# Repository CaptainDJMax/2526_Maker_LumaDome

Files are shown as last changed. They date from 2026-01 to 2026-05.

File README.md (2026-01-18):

# 2526_Maker_LumaDome

##  Présentation du projet
**LumaDome** est une lampe d'ambiance connectée et intelligente. L'objectif est d'allier esthétique et technique pour afficher des messages dynamiques. Conçue comme un objet design hybride, elle associe une base imprimée en 3D, un abat-jour textile structuré par découpe laser et l'électronique sur mesure et la gestion d'énergie.

Au-delà de l'esthétique, l'objectif est de créer une interface lumineuse capable de :
* Afficher des **notifications visuelles** (ex: simulateur d'aube au réveil).
* Diffuser des **messages personnalisés** envoyés en Bluetooth depuis un smartphone.
* Être totalement **nomade** grâce à une batterie intégrée.

## 🛠 Architecture Technique
Ce projet mobilise 4 axes principaux :
1.  **Mécanique :** Base cylindrique (Impression 3D) contenant l'électronique + Structure haute (Découpe Laser) supportant le textile.
2.  **Électronique :** PCB sur mesure avec microcontrôleur (type ESP32) pour la gestion LED et Bluetooth.
3.  **Énergie :** Système autonome sur batterie LiPo avec gestion de charge (BMS).
4.  **Habillage :** Travail du textile (Couture) pour la diffusion de la lumière.

##  Rétroplanning Prévisionnel 🔗[02_Gestion_Projet/RetroPlanning.md]

[Cliquez ici pour voir le rétroplanning complet et détaillé](./02_Gestion_Projet/RetroPlanning.md)

Ce planning s'aligne sur les séances de formation technique du semestre.

| Date | Phase | Objectifs spécifiques LumaDome |
| :--- | :--- | :--- |
| **19 Janv** | CAD (Conception) | Modélisation 3D de la base (support PCB) et esquisse de la structure laser. |
| **22 Janv** | 3D Print | Lancement de l'impression du prototype de la base. |
| **26 Janv** | Laser Cut | Découpe du squelette/cadre pour l'abat-jour. |
| **29 Janv** | PCB Design | Conception de la carte électronique (ESP32 + Driver LED). |
| **05 Fév** | Batterie (LiPo) | Dimensionnement de la batterie et intégration du BMS. |
| **09 Fév** | Couture | Patronage et assemblage du tissu sur la structure laser. |
| **Fév - Mars** |  Code & Finalisations| Développement du firmware (Bluetooth & Animations) + finalisation des choses pas terminer|
| **Avril** | Finalisation | Assemblage final, finitions et tournage vidéo. |

```mermaid
gantt
    title Rétro-Planning LumaDome (2026)
    dateFormat  YYYY-MM-DD
    axisFormat  %d/%m
    excludes    weekends

    section Phase 1 : Formation & Proto
    Git & Concept (Fait)       :done,    p1_git, 2026-01-15, 1d
    CAD Base 3D (En cours)     :active,  p1_cad, 2026-01-19, 3d
    3D Print (Lancement)       :         p1_3d,  2026-01-22, 1d
    Laser Cut (Structure)      :         p1_las, 2026-01-26, 3d
    PCB Design (KiCad)         :         p1_pcb, 2026-01-29, 4d
    Soudure & Routage          :         p1_sou, 2026-02-02, 3d
    Batterie LiPo & BMS        :         p1_bat, 2026-02-05, 4d
    Couture (Habillage)        :         p1_cou, 2026-02-09, 5d

    section Phase 2 : Dév. LumaDome
    Intégration Méca/Elec      :         p2_int, 2026-02-16, 3d
    Code (Hello World LED)     :         p2_dev1, 2026-02-19, 10d
    Code (Bluetooth BLE)       :         p2_dev2, 2026-03-09, 3d
    Debug & Tests Autonomie    :         p2_deb, 2026-03-12, 4d
    Finitions Tissu            :         p2_fin, 2026-03-16, 3d
    Code (Animations)          :         p2_dev3, 2026-03-19, 4d
    Assemblage Final           :         p2_ass, 2026-03-23, 3d
    Tournage Vidéo             :         p2_vid, 2026-03-26, 4d
    Derniers ajustements       :         p2_adj, 2026-03-30, 7d
    Prép. Soutenance           :         p2_sou, 2026-04-02, 7d
    
    section Jalons
    SOUTENANCE FINALE          :crit, milestone, 2026-04-13, 0d
```
---

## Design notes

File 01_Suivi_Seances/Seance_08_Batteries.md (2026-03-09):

# Séance 8 : 19 Février 2026 - Utilisation et Fabrication de Batteries

##  Objectifs de la séance
* Comprendre les différentes chimies de batteries (Li-ion, LiFePO4).
* Maîtriser le dimensionnement électrique (Capacité, Taux de décharge "C", Série/Parallèle).
* Apprendre les règles de sécurité et les étapes de fabrication d'un pack batterie sur mesure.

##  Résumé du cours

### 1. Pourquoi fabriquer sa propre batterie ?
Créer son propre pack présente plusieurs avantages majeurs :
* **Forme sur mesure :** Permet d'adapter parfaitement la batterie à la coque de notre projet (ex: intégration dans un dôme).
* **Maîtrise du processus :** On choisit la qualité des composants et on réduit les coûts.
* **Écologie / Sécurité :** L'usage de piles rechargeables est beaucoup plus pertinent et économique à long terme (notamment pour les jouets d'enfants ou les gros projets).

### 2. Les chimies et tensions nominales
Il est vital de connaître la chimie pour bien configurer son chargeur et son BMS :
* **Lithium-Ion (Li-ion) :** Tension nominale d'environ **3.7V** (varie de 3.0V vide à 4.2V pleine).
* **Lithium Fer Phosphate (LiFePO4) :** Tension nominale d'environ **3.2V** (chimie très stable et sécurisée).

### 3. Le Taux de décharge / charge (Le "C-Rate")
*Note sur la Slide 11 du cours :*
Le "C" représente la **Capacité** de la batterie. Il définit les limites de courant qu'elle peut encaisser.
* **Décharge (Max Discharge Rate) :** Si une batterie de 4000 mAh a une décharge de 30C, le courant maximal autorisé est : $4 \text{ Ah} \times 30 = \mathbf{120 \text{ Ampères}}$.
* **Charge (Max Charge Rate) :** Une indication de "3C" signifie qu'on peut la charger à 3 fois sa capacité (ici 12A). *Règle de sécurité :* Si on ne connaît pas la valeur, on charge toujours à **1C maximum** pour ne pas abîmer la cellule.

### 4. Configuration S et P
L'assemblage des cellules définit la puissance du pack :
* **S (Série) :** Additionne la tension. Exemple : "4S" = 4 batteries à la suite.
* **P (Parallèle) :** Additionne la capacité (et le courant de décharge). "4S1P" signifie un pack de 4 batteries en série, avec une seule rangée (pas de cellules doublées).

## 🛠️ Travaux Pratiques : Le Pack Batterie LumaDome
Pour mon projet, j'ai besoin d'une alimentation capable de délivrer **12V et au moins 5A** pour alimenter le convertisseur Buck des LEDs NeoPixel.

**Choix technique :** J'ai opté pour un **Pack 4S** (4 cellules en série).
* *Cellules utilisées :* Samsung INR18650-35E (3.7V, 3450mAh, décharge 8A).
* *Protection :* Un BMS 4S 20A sera intégré pour équilibrer la charge et protéger contre les courts-circuits.

**État d'avancement du TP :**
Je n'ai pas encore procédé à la soudure par points des lamelles de nickel. Actuellement, je me concentre sur la conception mécanique.
* **Modélisation 3D :** Je suis en train de designer la coque (support de batterie) sur CAD. Cette pièce imprimée en 3D permettra d'accueillir et de caler fermement les 4 piles avant de procéder à l'assemblage définitif (Soudure, BMS, Kapton et Gaine thermorétractable).

## ✅ Tâches effectuées
- [x] Dimensionnement du pack batterie pour le projet (Configuration 4S).
- [x] Début de la conception 3D du support de piles 18650.
- [ ] Impression 3D du support (À faire).
- [ ] Soudure par points et assemblage du pack (À faire).

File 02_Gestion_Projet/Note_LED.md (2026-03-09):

###  Note Technique : Dimensionnement des LEDs (Ref: Adafruit 1138)

#### 1. Choix du Matériel (Éclairage)
* **Référence retenue :** Adafruit 1138-4m (NeoPixel Digital RGB LED Strip - White PCB).
* **Spécifications :** Alimentation **5V DC**, densité standard de **60 LEDs/mètre**, adressables individuellement (WS2812B/SK6812).
* **Avantages :** La bobine de 4 mètres permet de couvrir le projet avec une seule bande .

#### 2. Calculs de Dimensionnement (Surface & Longueur)
Pour créer une grille lumineuse homogène sur la surface du LumaDome ($31 160.67 \text{ mm}^2$) :
* **Espacement :** À 60 LEDs par mètre, l'écart entre chaque puce LED est de **16.5 mm**.
* **aire LED théorique :** Longueur x largeur = $16,5 * 12,5$ = **206,25 mm²**.
* **Verdict :** Pour tapisser parfaitement la surface, environ $31 160.67 / 206,25 = 152$ LED nécessaires. L'achat de la bobine de 4 mètres garantit d'avoir suffisamment de matière.

#### 3.  Bilan de Puissance & Électronique.
* **Consommation (pour 125 LED) :** Chaque LED consomme jusqu'à 60mA (en blanc luminosité max). $125 \times 0.06\text{A}$ = **7.5 Ampères** (soit environ 37.5 Watts).

#### 4. Intégration sur le PCB
* **Alimentation (Convertisseur Buck) :** Pour passer de la batterie 4S (~14.8V) au 5V requis par les LEDs, un module Step-Down 5V capable de fournir **10 Ampères** de manière stable sera parfait (il y a une bonne marge de sécurité).
* **Routage KiCad :** Un courant de 7.5 A est parfaitement gérable, mais il faut appliquer la règle de dimensionnement vue en cours : **1 Via supporte environ 1 Ampère**. Il faudra donc utiliser des pistes d'alimentation larges et placer plusieurs Vias pour les changements de couche.

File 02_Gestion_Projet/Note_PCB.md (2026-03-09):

# Note Technique : Nomenclature (BOM) et Rôle des Composants du PCB

Cette note détaille l'ensemble des composants nécessaires à la conception du circuit imprimé (PCB) du LumaDome, ainsi que leur rôle spécifique dans l'architecture électronique.

## Nomenclature des composants (BOM)

| Catégorie | Composant | Référence / Détails | Rôle principal |
| --- | --- | --- | --- |
| **Énergie** | **Secteur 12V** | Bloc alimentation DC 12V (2.5 A) | Alimentation fixe (Jack DC). |
| **Énergie** | **Batterie 4S** | 4x 18650 Samsung INR18650-35E | Source nomade (**14.8V** nominal). |
| **Énergie** | **Régulateur 5V** |  | Alimente les LEDs (conversion 16V -> 5V). |
| **Énergie** | **Régulateur 3.3V** |  | Alimente l'ESP32 (conversion 5V -> 3.3V). |
| **Cerveau** | **Microcontrôleur** | **ESP32-WROOM-32E-N4** | Cerveau Wi-Fi/BT et gestion des LEDs. |
| **Interface** | **Connecteur JTAG** | **Header 2x5 (10 pins)** | Interface pour l'ESP-Prog 2 (Debug/Flash). |
| **Interface** | **Connecteur LED** | Bornier ou JST SM 3 pins | Sortie vers le ruban Adafruit 1138. |
| **Logique** | **Level Shifter** | **SN74AHCT125** | Traduit le signal Data 3.3V vers 5V. |
| **Contrôle** | **Boutons** | Poussoirs tactiles 6mm | Mode, Luminosité, Reset, Boot. |
| **Outil** | **ESP-Prog 2** | Programmateur | Programmateur externe USB. |

---

## 1.  Le Cerveau et la Programmation

* **Le Microcontrôleur : ESP32-WROOM-32E-N4**
  * *Rôle :* C'est le cerveau du projet. Il exécute le code en C (ESP-IDF), génère les signaux pour animer les LEDs, et lit les appuis sur les boutons. Il intègre nativement le Wi-Fi et le Bluetooth.
* **Le Connecteur JTAG / UART : Header 2x5 pins/broches (Pas de 2.54mm ou 1.27mm)**
  * *Rôle :* C'est la "prise diagnostic" du PCB. Elle permet de relier la carte à l'ordinateur pour injecter le code et lire les erreurs.
* **Le Programmateur Externe : ESP-PROG-2**
  * *Rôle :* Outil physique officiel d'Espressif (qui ne reste pas sur la lampe). Il fait le pont entre le port USB de l'ordinateur et le connecteur JTAG du PCB pour flasher et déboguer le code de l'ESP32.

## 2.  L'Alimentation et l'Énergie

* **L'Entrée Secteur : Connecteur USB-C (avec module Trigger 12V)**
  * *Rôle :* Permet de brancher un chargeur mural standard (fournissant du 12V DC) pour utiliser la lampe à la maison sans vider la batterie.
* **L'Entrée Batterie : Connecteur JST**
  * *Rôle :* Relie le pack batterie maison 4S (14.8V nominal / 16.8V max) au circuit.
* **Le Sélecteur de Source : Interrupteur à bascule (SPDT - 3 broches)**
  * *Rôle :* Sécurité matérielle. Il permet de basculer physiquement l'alimentation de la lampe soit sur la Batterie, soit sur le Secteur, empêchant les deux de se court-circuiter.
* **Le Grand Régulateur 5V**
  * *Rôle :* Il prend le 12V (secteur) ou le 16.8V (batterie) et le rabaisse à un **5V** très puissant (capable de fournir au moins 7 à 10 Ampères) pour alimenter l'intégralité du ruban LED.
* **Le Petit Régulateur 3.3V**
  * *Rôle :* Il prend le 12V et le rabaisse en un **3.3V** très propre et stable, uniquement pour l'ESP32 qui ne supporte pas le 5V.

## 3.  Interface et Lumière

* **Le Level Shifter : SN74AHCT125N (ou 74AHCT125D en CMS)**
  * *Rôle :* Convertisseur de niveau logique ("traducteur"). L'ESP32 envoie les ordres de couleurs en 3.3V, mais les LEDs exigent un signal de 5V. Ce composant rehausse le signal instantanément pour éviter que les LEDs ne clignotent de manière erratique.
* **Le Connecteur Ruban LED : Connecteur JST SM (3 broches) ou Bornier à vis**
  * *Rôle :* Permet de brancher (et débrancher facilement) les 3 fils du ruban Adafruit 1138 (5V, Data, GND) à la carte mère.
* **Boutons Utilisateur : Boutons Poussoirs Tactiles (6x6mm)**
  * *Bouton "Mode" :* Relié à une broche de l'ESP32 pour changer les animations (ex: fondu, clignotement, couleur fixe).
  * *Bouton "Luminosité" :* Relié à une autre broche pour cycler entre différents niveaux d'intensité (ex: 25%, 50%, 100%).
* **Boutons Système : Boutons Poussoirs Tactiles**
  * *Bouton "Reset" (EN) :* Redémarre l'ESP32.

---

##  🛠️ Focus : Le Connecteur JTAG (2x5 pins)

Pour le LumaDome, nous abandonnons le connecteur UART simple pour une interface **JTAG professionnelle**. Cela permet non seulement de flasher le code, mais aussi de faire du **débogage en temps réel** (arrêt sur image du code, lecture des variables).

### A. Choix matériel

* **Type :** Barrette de broches mâle (**Pin Header 2x5**).
* **Pas (Pitch) :** **2.54 mm** (choisi pour la facilité de soudure manuelle).
* **Câblage :** Relié au port "JTAG" de l'**ESP-Prog 2** via une nappe 10 fils.

### B. Plan de connexion (Netlist) vers l'ESP32

Ce tableau définit comment relier le connecteur 2x5 aux broches du module ESP32-WROOM-32E dans KiCad :

| Broche Connecteur (2x5) | Signal JTAG | Broche ESP32-WROOM | Fonction |
| --- | --- | --- | --- |
| **1** | **VDD** | **3V3** | Alimentation logique |
| **2** | **TMS** | **GPIO 14** | Test Mode Select |
| **3** | **GND** | **GND** | Masse |
| **4** | **TCK** | **GPIO 13** | Test Clock |
| **5** | **GND** | **GND** | Masse |
| **6** | **TDO** | **GPIO 15** | Test Data Out |
| **7** | **NC** | - | Non connecté |
| **8** | **TDI** | **GPIO 12** | Test Data In |
| **9** | **GND** | **GND** | Masse |
| **10** | **RESET** | **EN** | Hard Reset automatique |

---

## 3. 💡 Recommandations pour la conception du PCB

###  Routage et Signaux

* **Détrompeur :** Marquer la **broche 1** sur le PCB avec un petit triangle blanc en sérigraphie pour éviter de brancher la nappe à l'envers.
* **Intégrité du signal :** Les pistes JTAG (TDI, TDO, TCK, TMS) transportent des signaux rapides. Il faut les router de manière directe et éviter de les faire passer trop près du régulateur Buck 5V pour limiter les parasites.

###  Gestion de la Puissance

* **Largeur des pistes :** Pour les 112 LEDs (consommation max **7,5 A**), utiliser des pistes de puissance d'au moins **3-4 mm** de large ou un plan de cuivre complet sur la face arrière.

---

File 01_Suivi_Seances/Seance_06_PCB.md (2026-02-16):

# Séance 6 : 2 Février 2026 - Conception de Circuit Imprimé (PCB)

##  Objectifs de la séance
* Comprendre la structure physique d'un PCB (Couches, FR4, Cuivre).
* Appréhender les bus de communication (UART, I2C, SPI).
* Maîtriser les règles de conception (Schematic & Layout) sous KiCad.
* Focus spécifique sur l'intégration de l'USB-C et les protections ESD.

##  Résumé du cours

### 1. Anatomie d'un PCB
Un circuit imprimé est un sandwich de plusieurs couches[cite: 19]:
* **Substrat  :** L'isolant rigide (fibre de verre + époxy) qui sert de support.
* **Cuivre (Copper) :** Les pistes conductrices. On parle de couches "Top" (Dessus) et "Bottom" (Dessous).
* **Vernis épargne (Soldermask) :** La couche (souvent verte) qui protège le cuivre et empêche l'étain de baver.
* **Sérigraphie (Silkscreen) :** Le texte blanc pour identifier les composants.

### 2. Workflow sous KiCad
La conception se fait en deux temps:
1.  **Schématique (Schematic) :** On dessine la logique du circuit avec des symboles.
2.  **Routage (Layout/PCB New) :** On transforme les symboles en empreintes physiques (Footprints) et on trace les pistes en cuivre.

### 3. Focus Technique : USB-C et Protections
Pour intégrer un port USB-C proprement (exemple pour alimenter notre carte), il faut respecter certaines règles dictées par le standard :
* **Réversibilité :** Pour que le câble fonctionne dans les deux sens, il faut connecter les broches **CC1** et **CC2** à la masse via deux résistances de **5.1kΩ** distinctes. Cela indique au chargeur qu'il doit fournir du 5V.
* **Protection ESD (Électrostatique) :** L'ajout d'un composant comme le **USBLC6-SC6** (réseau de 5 diodes) est recommandé pour protéger les lignes de données contre les pics de tension ou les mauvais branchements.
* **Diode TVS :** À placer sur l'alimentation pour absorber les surtensions transitoires.

### 4. Bonnes pratiques de Routage
* **Découplage :** Les condensateurs de découplage doivent être placés **au plus près** des broches d'alimentation du composant pour être efficaces.

* **Signaux rapides (USB/Data) :** Il faut router les pistes paires (D+/D-) avec la même longueur (Paires différentielles) pour éviter les décalages de signal.
* **Courant & Vias :**
    * Une règle empirique à retenir : **1 Via standard supporte environ 1A**.
    * La largeur des pistes doit être adaptée au courant qui les traverse (utiliser un calculateur).
* **Unités :** Attention aux datasheets !
    * `mm` = Millimètres.
    * `mil` = Millième de pouce (100 mil = 2.54 mm).

### 5. Astuces KiCad
* **PWR_FLAG :** Symbole spécial à ajouter sur le schéma pour dire au logiciel "Ceci est une source d'alimentation" et éviter les erreurs du DRC (Design Rules Checker).
* **MPN (Manufacturer Part Number) :** Pour tout composant non générique (hors résistances/condensateurs classiques), il est crucial de renseigner la référence fabricant exacte dans les propriétés pour faciliter la commande (BOM).

## 🛠️ Travaux Pratiques 
Conception KiCad
1.  **Schématique :**
    * Intégration du CH334F et du Quartz 12 MHz.
    * Ajout des protections ESD (USBLC6-2) sur toutes les lignes de données.
    * Utilisation du symbole `PWR_FLAG` pour valider les entrées d'alimentation lors du check électrique (ERC).
2.  **Routage (Layout) - Règles Avancées :**
    * **Stackup 4 Couches :** Top (Signaux) / In1 (GND Plane) / In2 (Power Plane) / Bottom (Signaux + Pogo).
    * **Signal Integrity (USB High Speed 480Mbps) :**
        * **Length Matching (Skew) :** Ajustement des longueurs de pistes (D+ vs D-) via des "méandres" (zigzags) pour garantir une tolérance < 0.15mm.
    * **Mécanique :** Placement précis des Pogo-pins selon le DXF officiel du Raspberry Pi Zero.

###  État d'avancement
Le projet est en phase finale : Schéma validé, Routage terminé (y compris les méandres), DRC (Design Rule Check) en cours de correction.

##  Impact sur le projet LumaDome
Ce TP m'a permis de valider la conception USB-C. Pour mon projet personnel (LumaDome), j'appliquerai les mêmes règles (Résistances 5.1kΩ + USBLC6) pour la prise de charge et la programmation si besoin dans mon projet.

## ✅ Tâches effectuées
- [x] Cours théorique sur les bus (I2C, UART) et les couches PCB.
- [x] Analyse du schéma de référence pour l'USB-C (Résistances CC + ESD).
- [x] Saisie du schématique complet du Hub CH334F sous KiCad.
- [x] Placement et routage complexe (4 couches + Paires différentielles).
- [ ] Création du projet KiCad pour le LumaDome (À faire).

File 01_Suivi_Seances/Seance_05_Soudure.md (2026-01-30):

# Séance 5 : 29 Janvier 2026 - Soudure & Assemblage PCB

## Objectifs de la séance
* Comprendre la théorie du brasage (Soudure) : mouillage, flux, alliages.
* Apprendre le processus industriel CMS (Composants Montés en Surface).
* Pratiquer l'assemblage manuel (Fer à souder) et la refusion (Four).

## Résumé du cours
### 1. Théorie de la soudure
Le brasage est un procédé d'assemblage permanent établissant une liaison métallique.
* **Le Flux :** Indispensable, il sert à décaper les surfaces (enlever l'oxyde), favoriser le mouillage et protéger le métal lors de la chauffe.
* **Sécurité :** Les fumées de soudure sont nocives (colophane). Il faut impérativement travailler dans une zone ventilée et se laver les mains après manipulation (risque plomb).

### 2. Procédé CMS (Surface) vs Traversant
* **Soudure Manuelle (Traversant) :** On utilise un fer chauffé entre **350°C et 400°C**. La technique consiste à chauffer simultanément la pastille et la patte du composant avant d'apporter l'étain.
* **Procédé Reflow (CMS) :** Utilisé pour les composants de surface.
    * **Pâte à braser :** Mélange de billes d'étain et de flux. Elle a une durée de vie limitée une fois sortie du frigo.
    * **Stencil (Pochoir) :** Feuille d'inox découpée au laser permettant de déposer la pâte précisément sur les empreintes du PCB.
    * **Four à refusion :** Suit un profil thermique précis : Préchauffage (montée en température), Soak (activation du flux), Reflow (fusion de l'alliage) et Refroidissement.

## Travaux Pratiques : Assemblage PCB
*Travail réalisé en trinôme avec Elise FIRMIN et Emilie ZHENG.*

### Étape 1 : Composants CMS (Surface)
1.  **Dépôt de pâte :** Réalisé par les encadrants à l'aide du stencil.
2.  **Placement (Pick & Place) :**
    * Pendant que mes camarades récupéraient et triaient les composants nécessaires dans le FabLab, j'ai assuré le placement des composants sur le PCB.
    * =Utilisation de brucelles pour déposer les composants sur la pâte à braser sans l'étaler=.
3.  **Cuisson :** Passage de la carte dans le four à refusion pour braser tous les composants d'un coup.

### Étape 2 : Composants Traversants & Finitions
Après la sortie du four, nous avons terminé la carte manuellement :
* **Soudure au fer :** Fixation des connecteurs traversants (headers).
* **Cas particulier des Boutons Poussoirs :** Nous les avons soudés à la main **après** le passage au four.
    * *Raison technique :* Lors d'essais précédents, le plastique des boutons fondait à cause de la chaleur du four, rendant le mécanisme inopérant.

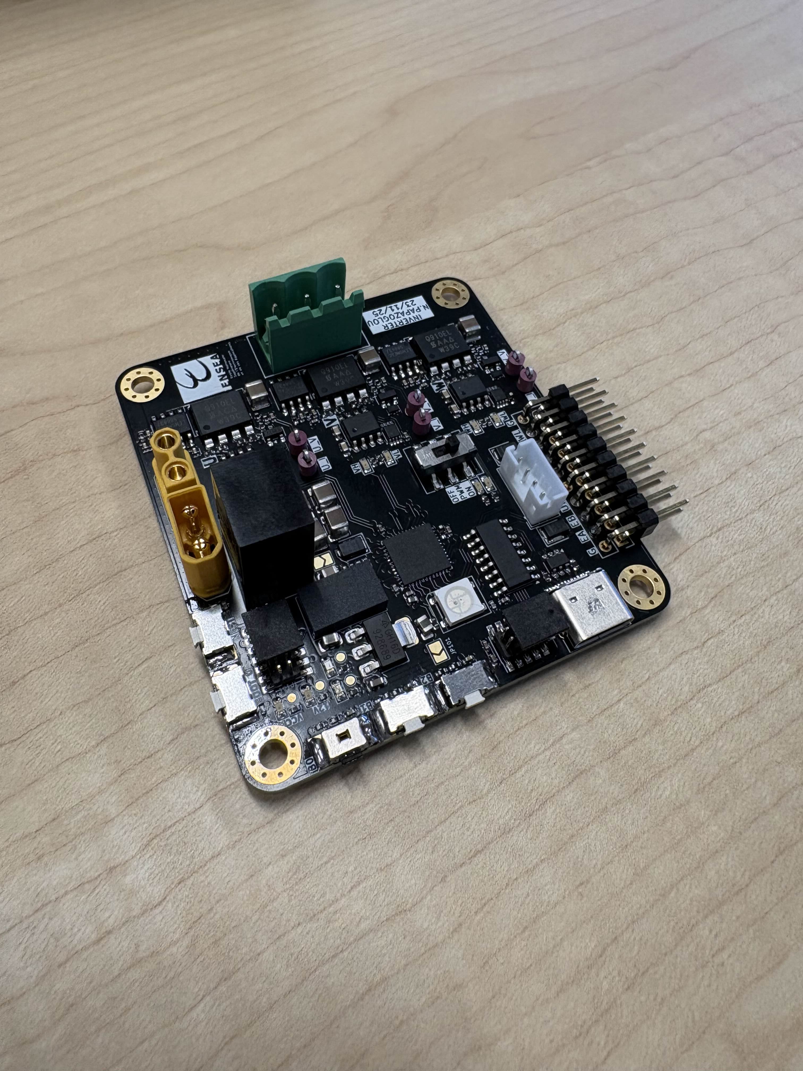
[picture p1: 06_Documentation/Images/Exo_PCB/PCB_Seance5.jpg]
Photo de notre PCB assemblé


## Notes importantes pour le Projet LumaDome

### Électronique (BOM)
Pour la commande des composants de mon projet personnel :
* Il faut impérativement renseigner la **référence fabricant (MPN - Manufacturer Part Number)** pour tous les composants (CI, Connecteurs, Leds).
* *Exception :* Pour les **résistances**, la valeur simple suffit (ex: 10kΩ, 220Ω).

### Mécanique (Vis)
Mise à jour des contraintes pour la modélisation 3D (Base) :
* Le stock disponible contient 1000 vis de **16mm**.
* **Action CAD :** Je dois adapter mes épaisseurs et rajouter **2mm** de marge aux joints d'assemblage pour être sûr que ces vis serrent correctement sans dépasser ou être trop courtes.

## ✅ Tâches effectuées
- [x] Placement des composants CMS sur pâte à braser.
- [x] Soudure manuelle des traversants.
- [x] Validation visuelle des joints de soudure (brillants et lisses).
- [ ] Mise à jour du BOM LumaDome avec les MPN.
- [ ] Correction du CAD Base (Tolérance vis 16mm).

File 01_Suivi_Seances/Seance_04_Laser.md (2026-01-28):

# Séance 4 : 26 Janvier 2026 - Découpe Laser

## Objectifs de la séance
* Comprendre le fonctionnement et les dangers d'une découpeuse laser CO2.
* Connaître les paramètres de coupe. 

## Résumé du cours

### 1. Principe et Machine
Nous utilisons une **Laser CO2** au FabLab.
* **Fonctionnement :** Un tube génère un faisceau laser (infrarouge) qui est dirigé par un jeu de miroirs jusqu'à la tête de découpe, où une lentille le focalise en un point très chaud.
* **Matériaux compatibles :** Principalement les matériaux organiques comme le bois (MDF, Contreplaqué), le carton, le cuir et les plastiques comme l'Acrylique (PMMA).
* **Sécurité & Environnement :**
    * C'est une machine de **Classe 4** (Risque d'incendie et de brûlure).
    * **Interdiction stricte :** Ne jamais couper de PVC ou Vinyle (dégage du chlore gazeux mortel pour l'homme et la machine).
    * **Ventilation :** Il y a de fortes odeurs après la découpe (bois brûlé/plastique fondu), il faut attendre avant d'ouvrir le capot.

### 2. Les 3 Paramètres Cruciaux
Pour réussir une découpe ou une gravure, il faut régler trois variables dans le logiciel :
1.  **Puissance (Power) :** L'intensité du rayon (en %). Trop fort = brûlures ; Trop faible = ne traverse pas.
2.  **Vitesse (Speed) :** La rapidité de déplacement de la tête.
    * *Coupe (Vecteur) :* Vitesse lente / Puissance élevée.
    * *Gravure (Raster) :* Vitesse rapide / Puissance modérée.
3.  **Fréquence (PPI/Hz) :** Le nombre d'impulsions par seconde. Une fréquence élevée donne un bord plus net (poli) sur l'acrylique.

### 3. Astuces de Conception
*  Le laser a une épaisseur (environ 0.1 - 0.2mm). Si on veut faire des gravures mettre une forte épaisseur au lieu d'épaisseur fine pour réaliser des gravures
* **Assemblages malins :**
    * *Notches :* Créneaux pour emboîter des plaques à 90°.
    * *Captive Nut (Écrou prisonnier) :* Découper une forme en "T" dans le bois pour y glisser un écrou métallique et pouvoir visser solidement (vu en cours).
    * *Living Hinge :* Motifs spécifiques permettant de plier du bois rigide.

##  Application au Projet LumaDome
La découpe laser servira à créer le **squelette** de l'abat-jour.

* **Design :** Conception de "couples" (comme sur un bateau) ou d'anneaux concentriques en MDF 3mm.
* **Assemblage :** Je vais utiliser la technique des **encoches (Notches)** pour assembler la structure laser sur la base imprimée en 3D.
* **Fixation Tissu :** Je prévois des petits trous dans la découpe laser pour pouvoir coudre le tissu directement sur le bois plus tard.

### TP Pratique : La "Useless Box"

En parallèle de l'apprentissage machine, j'ai réalisé un projet complet : une **Useless Box** . Ce projet m'a permis de lier la conception 3D et la fabrication réelle.

**1. Conception (Onshape) :**
J'ai modélisé l'intégralité du système avant fabrication pour valider les dimensions :
* **Le Boîtier :** Structure conçue pour être découpée au laser (assemblage par encoches/créneaux).
* **Les Supports Internes :** Conception sur mesure du support pour la pile et du berceau pour le moteur DC.
* **Le Mécanisme :** Modélisation du bras  qui vient physiquement basculer l'interrupteur pour inverser le sens de reotation du moteur et couper le circuit lors de la pose sur le levier à moustache.

**2. Composants utilisés :**
* Moteur DC + Support imprimé/découpé.
* Pile (Alimentation) + Logement.
* Interrupteur à levier (Toggle Switch).

**3. Assemblage & Résultat :**
Après la découpe et l'impression des supports, j'ai assemblé le tout. Le réglage de la course du levier (la moustache) a été l'étape clé pour qu'il touche parfaitement l'interrupteur.

**Galerie du projet :**

*Vue d'ensemble de la boîte fermée :*
Useless Box - Extérieur

*Vue interne (Mécanisme et Supports) :*
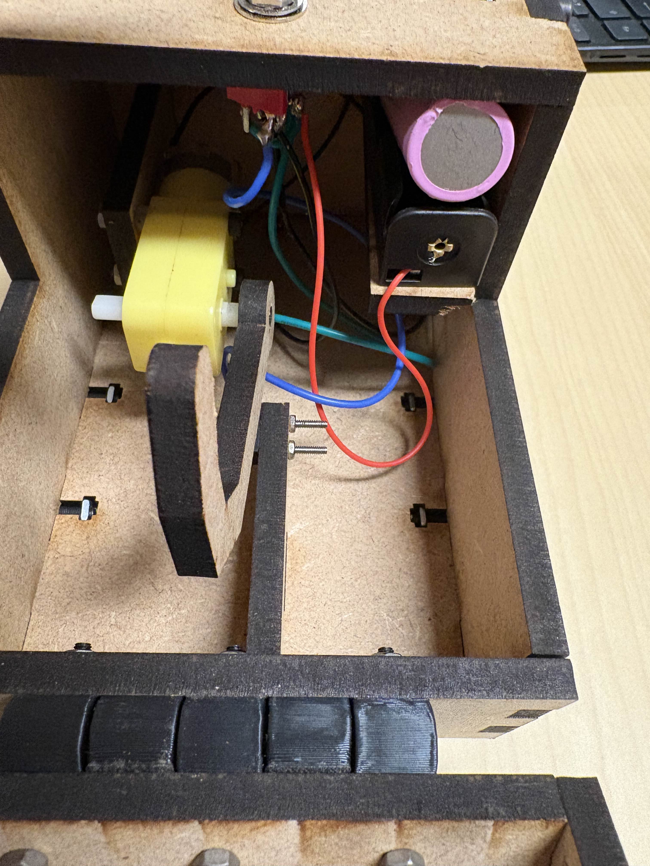
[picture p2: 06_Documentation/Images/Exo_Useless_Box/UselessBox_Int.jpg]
Mécanisme Interne


**Démonstration :**
[Vidéo du fonctionnement en action](../06_Documentation/Video/Exo_Useless_Box_video/Useless_Box_video.mov)

##  Tâches effectuées
- [x] Formation sécurité sur la découpeuse laser CO2.
- [x] Test des paramètres (Vitesse/Puissance) sur une chute de MDF.
- [x] TP mise en pratique "Useless Box" (Vitesse/Puissance).

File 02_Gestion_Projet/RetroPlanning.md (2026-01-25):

# Rétro-Planning : Projet LumaDome

Ce document détaille la feuille de route pour la réalisation du **LumaDome**, de la conception initiale à la soutenance finale. Il est divisé en blocs techniques (WBS - Work Breakdown Structure) suivis du calendrier chronologique.

---

## 1. Décomposition des Tâches Techniques (Détails)

Le travail est découpé par pôles de compétences.

### A. Mécanique & Structure (CAD / 3D / Laser)
L'objectif est de créer une base stable et une structure légère pour le diffuseur.
- [ ] **Modélisation Base :**
    - Conception du logement batterie (dimensions LiPo à vérifier).
    - Fixations pour le PCB (entretoises ou inserts).
    - Passage de câbles et port de charge (USB-C / Jack).
- [ ] **Modélisation Structure Haute :**
    - Design du cadre du dôme pour la découpe laser (Squelette).
    - Système de fixation (clips ou emboîtement) entre la base 3D et le squelette laser.
- [ ] **Prototypage :**
    - Impression 3D basse résolution (Draft) pour valider les dimensions.
    - Test de tolérance pour l'assemblage Base/Dôme.

### B. Électronique (PCB / Alimentation)
Le cœur du système
- [ ] **Conception Schématique (KiCad) :**
    - Intégration Bluetooth.
    - Circuit de gestion puissance.
    - Connecteurs (Batterie, LEDs, Boutons).
- [ ] **Routage PCB :**
    - Placement des composants pour optimiser l'espace dans la base cylindrique.
    - Largeur de pistes adaptée au courant (Ampérage) des LEDs.
    - Plan de masse (GND) pour la stabilité du signal.
- [ ] **Énergie :**
    - Choix de la batterie LiPo.
    - Soudure et gaine thermorétractable du BMS (Battery Management System).

### C. Habillage & Finitions (Couture)
La tissu du projet qui diffusera la lumière.
- [ ] **Recherche matériaux :** Test de diffusion lumière à travers différents tissus (Lycra, Coton, Synthétique).
- [ ] **Patronage :** Création du patron "à plat" correspondant à la forme courbe du dôme.
- [ ] **Assemblage :** Couture et fixation sur la structure découpe laser.

### D. Développement Logiciel (Firmware)
Le code embarqué PCB.
- [ ] **Briques de base :**
    - Driver LED.
    - Gestion du Bluetooth pour communication Smartphone.
- [ ] **Fonctionnalités avancées :**
    - Modes d'animation (Arc-en-ciel, Respiration, Aube).
    - Stockage des préférences (Mémoire EEPROM/SPIFFS).
    - Gestion de l'énergie (Deep Sleep).

---

##  2. Calendrier Prévisionnel (Timeline)

Ce planning respecte les jalons imposés par l'Option Maker.

###  Phase 1 : Apprentissage & Conception (Janvier - Février)

| État | Date | Thème | Tâches LumaDome à valider |
| :---: | :--- | :--- | :--- |
| [x] | **Jeu 15 Janv** | **Git** | Initialisation Repo, Arborescence, Idée validée. |
| [x] | **Lun 19 Janv** | **CAD** | **LIVRABLE :** Plans 3D de la base (Logement élec). |
| [x] | **Jeu 22 Janv** | **3D Print** | Cours théorique + Configuration Slicer (PLA). |
| [ ] | **Lun 26 Janv** | **Laser** | Découpe du squelette du dôme (Medium/Plexi). |
| [ ] | **Jeu 29 Janv** | **PCB (1)** | Schématique électronique terminée sur KiCad. |
| [ ] | **Lun 02 Fév** | **Soudure** | Routage terminé + Génération fichiers Gerber. |
| [ ] | **Jeu 05 Fév** | **LiPo** | Choix batterie + Test chargeur/BMS. |
| [ ] | **Lun 09 Fév** | **Couture** | Premier essai d'habillage textile sur structure. |

###  Phase 2 : Développement & Intégration (Février - Avril)

| État | Date | Type | Objectifs de séance |
| :---: | :--- | :--- | :--- |
| [ ] | **Lun 16 Fév** | Encadré | **Intégration Méca/Élec :** Vérifier que tout rentre dans la base. |
| [ ] | **Jeu 19 Fév** | Libre | **Code :** Premier allumage des LEDs (Hello World lumineux). |
| [ ] | **Lun 09 Mar** | Encadré | **Code :** Mise en place du Bluetooth (BLE). |
| [ ] | **Jeu 12 Mar** | Libre | **Debug :** Tests d'autonomie batterie. |
| [ ] | **Lun 16 Mar** | Encadré | **Finitions :** Optimisation diffusion lumière (Tissu). |
| [ ] | **Jeu 19 Mar** | Encadré | **Code :** Animations fluides et transitions. |
| [ ] | **Lun 23 Mar** | Encadré | **Assemblage Final :** Collage, vissage, cable management propre. |
| [ ] | **Jeu 26 Mar** | Libre | Tournage et montage **Vidéo Insta (90s)**. |
| [ ] | **Lun 30 Mar** | Encadré | Derniers ajustements code/finitions. |
| [ ] | **Jeu 02 Avr** | Encadré | Préparation support de soutenance. |
| [ ] | **Jeu 09 Avr** | Libre | Répétition générale. |
| [ ] | **Lun 13 Avr** | **JURY** | **SOUTENANCE FINALE** |

---

##  3. Suivi Budgétaire (Budget Max : 100€)

---

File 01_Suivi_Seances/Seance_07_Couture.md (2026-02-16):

# Séance 7 : 9 Février 2026 - Initiation à la Couture

##  Objectifs de la séance
* Reconnaître les différents textiles (Fibres naturelles vs synthétiques).
* Comprendre la structure des tissus (Tissé vs Tricoté) et le sens du droit-fil.
* Prendre en main une machine à coudre et réaliser un assemblage simple.

##  Résumé du cours

### 1. Théorie des Matériaux
Nous avons appris à distinguer les types de textiles pour choisir le bon matériau selon le projet :
* **Les Fibres :**
    * *Naturelles :* Végétales (Coton, Lin, Bambou) ou Animales (Laine, Soie).
    * *Synthétiques :* Polyester (issu du pétrole, remplace le coton) ou Viscose (artificiel, remplace la soie).
* **La Structure :**
    * *Tissé (Woven) :* Entrecroisement de fils de chaîne et de trame. C'est stable mais ça s'effiloche.
    * *Tricoté (Knitted) :* Constitué de boucles (mailles). C'est extensible (stretch).

### 2. Les Outils Indispensables
La couture demande un outillage spécifique :
* **Ciseaux Tailleur :** À lame plate, pour couper le tissu à plat sur la table.
* **Ciseaux Cranteurs :** Lames en zig-zag, utilisés pour éviter que le tissu ne s'effiloche sur les bords.
* **Découd-vite :** L'outil essentiel pour corriger les erreurs.

### 3. La Machine à Coudre
Fonctionnement de base : L'aiguille entraîne le fil supérieur (bobine) qui vient se nouer avec le fil inférieur (**canette**) grâce au crochet rotatif.
Règle de sécurité : Ne jamais mettre les doigts sous l'aiguille et toujours porter des chaussures fermées (risque de chute d'aiguille ou ciseaux).

## 🛠️ TP Pratique : La Pochette de Téléphone
Pour valider les acquis, j'ai réalisé une pochette de protection sur mesure.

**Protocole de fabrication :**
1.  **Patronage :** Traçage du rectangle aux dimensions du téléphone + **3 cm de marge** de couture.
2.  **Découpe :** Utilisation des ciseaux cranteurs pour une finition propre des bords.
3.  **Préparation :** Création des ourlets et des languettes pour le passage du cordon.
4.  **Assemblage :** Couture **"Endroit contre Endroit"** (les jolis côtés du tissu se font face à l'intérieur) au point arrière ou à la machine, puis retournement de la pièce finale.

Ma pochette de téléphone finie

##  Impact sur le projet LumaDome
Cette séance confirme la faisabilité de l'abat-jour en tissu pour ma lampe.
* **Choix du tissu :** Je vais m'orienter vers un **Coton blanc fin (Tissé)** pour assurer une bonne diffusion de la lumière des LEDs tout en restant rigide sur la structure.
* **Technique :** J'utiliserai la technique de l'ourlet pour créer des fourreaux et glisser les tiges de la structure découpée au laser.

## ✅ Tâches effectuées
- [x] Découverte de la machine à coudre (Enfilage fil & Canette).
- [x] Exercice de couture droite sur chute de tissu.
- [x] Réalisation complète de la pochette de téléphone.

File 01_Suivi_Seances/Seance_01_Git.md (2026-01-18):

# Séance 1 : 15 Janvier 2026 - Introduction et Git

## Objectifs de la séance
* Comprendre le fonctionnement de l'Option Maker et les livrables attendus.
* Appréhender les outils de versionning (Git & GitHub).
* Définir le sujet du projet individuel.

## Résumé du cours
### 1. Présentation de l'Option Maker
Nous avons passé en revue les règles et le planning du semestre.
* **Philosophie :** "Apprentissage par le faire" et prototypage rapide.
* **Contraintes :**
    * Budget max : 100€ / étudiant.
    * Interdiction d'utiliser un Drive, tout doit passer par GitHub.
    * Le dépôt doit être **Public** pour favoriser l'Open Source.
* **Livrables finaux :** Code source, Rapport de documentation (GitHub) et une vidéo courte type Instagram (90s).

### 2. Atelier Git & GitHub
Nous avons étudié le support de cours sur Git pour comprendre la différence entre Git (local) et GitHub (cloud).
Points clés abordés :
* **Configuration :** Mise en place du nom d'utilisateur et de l'email (`git config`).
* **Sécurité :** Importance des clés SSH pour l'authentification sans mot de passe.
* **Workflow de base :**
    * `git init` : Initialiser un dépôt.
    * `git add` & `git commit` : Valider des modifications.
    * `git push` : Envoyer sur le serveur distant.
* **Documentation :** Utilisation du format **Markdown** pour rédiger les rapports (Titres, listes, code).

## 💡 Avancement du Projet : LumaDome
Suite au brainstorming, j'ai validé le concept de mon projet :
* **Nom du dépôt :** `2526_Maker_LumaDome`.
* **Idée :** Conception d'une lampe design intégrant un dôme LED miniature (inspiré de la Sphere de Las Vegas).
* **Fonctionnalités visées :** Affichage de messages défilants, animations lumineuses, structure imprimée en 3D et cadre découpé au laser.

## ✅ Tâches effectuées
- [ ] Création du compte GitHub et du dépôt public.
- [ ] Ajout du fichier `.gitignore` pour filtrer les fichiers inutiles.
- [ ] Mise en place de l'arborescence des dossiers.
- [ ] Mise en place du rétroplanning.

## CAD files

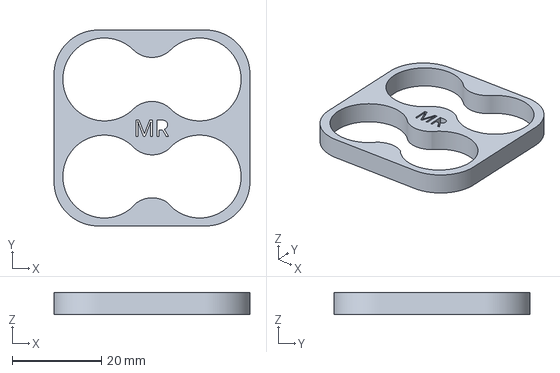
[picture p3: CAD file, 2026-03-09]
03_Mecanique/3D_Print/Part Studio 1 (2).3mf
44.0 x 44.0 x 5.00 mm

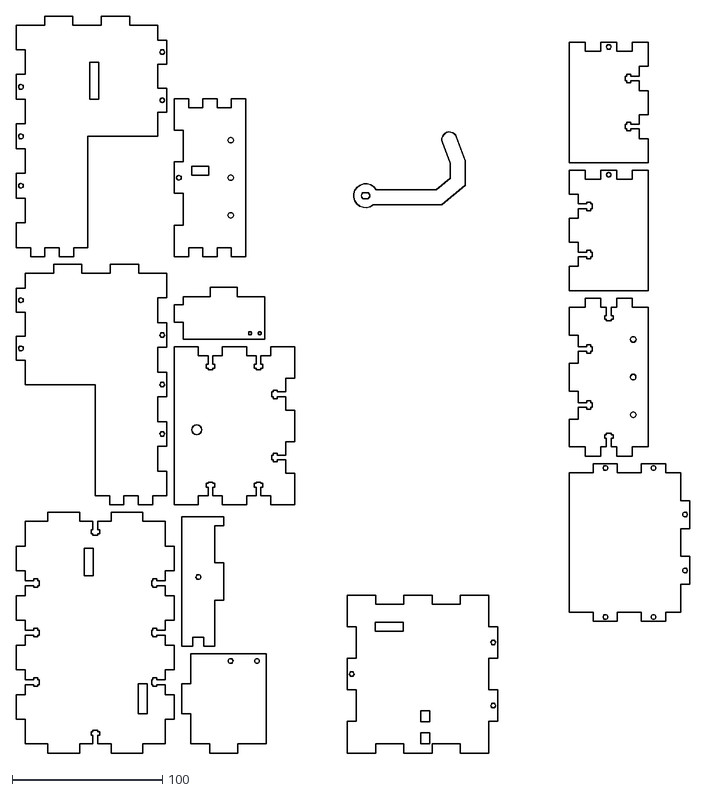
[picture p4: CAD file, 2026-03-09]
03_Mecanique/Laser_Cut/Drawing 1.dxf
447.6 x 490.0

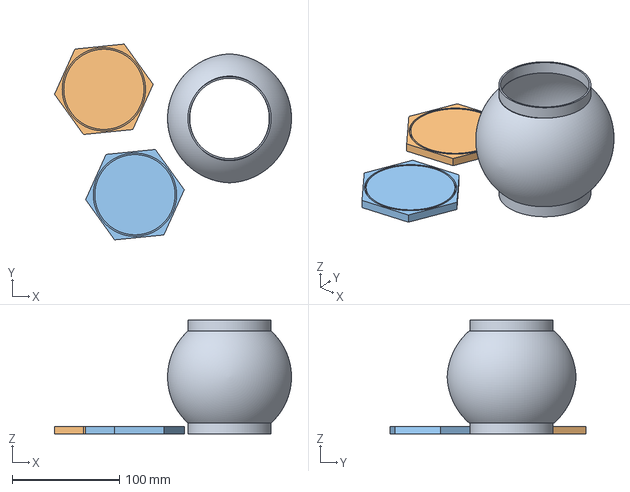
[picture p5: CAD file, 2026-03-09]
03_Mecanique/3D_Print/Socle dome.3mf
220.7 x 182.3 x 106.0 mm
Dome (1).stl
Socle dome (1).stl x 2

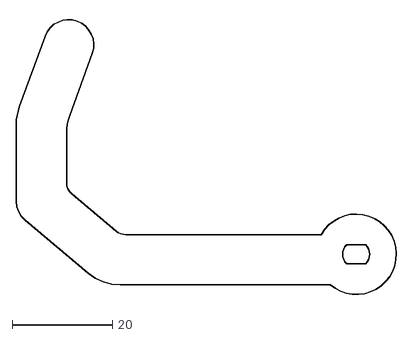
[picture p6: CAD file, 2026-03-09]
03_Mecanique/Laser_Cut/Drawing 2 (2).dxf
76.2 x 56.0

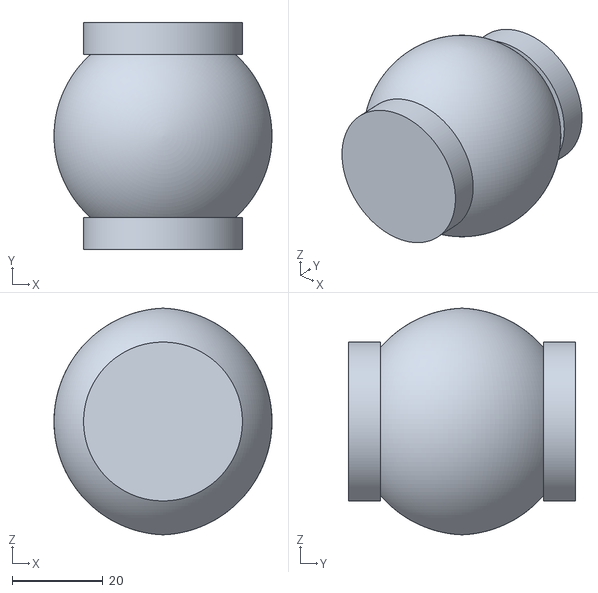
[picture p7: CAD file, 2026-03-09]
03_Mecanique/3D_Print/First Dome 5cm.stl
48.0 x 50.0 x 50.0

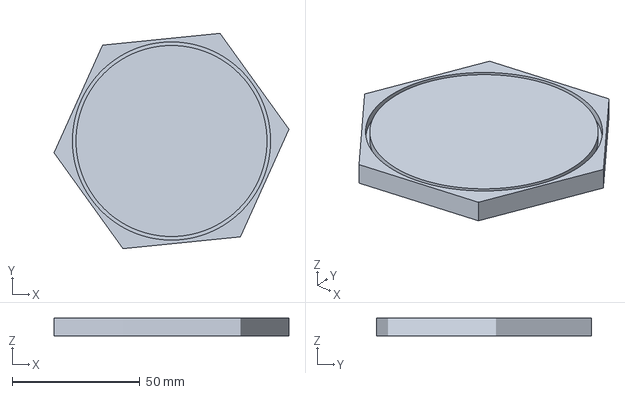
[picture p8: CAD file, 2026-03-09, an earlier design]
03_Mecanique/3D_Print/Socle dome (1).3mf
91.9 x 84.2 x 7.00 mm

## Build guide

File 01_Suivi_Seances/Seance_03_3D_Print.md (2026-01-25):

# Séance 3 : Impression 3D (FDM)

## Objectifs de la séance
* Comprendre le fonctionnement d'une imprimante 3D FDM (Dépôt de fil).
* Connaître les différents matériaux (PLA, PETG, ABS, TPU) et leurs usages.
* Maîtriser le **Slicing** (Tranchage) pour préparer un fichier à l'impression.

## Résumé du cours

### 1. Principe de fonctionnement (FDM)
La technologie utilisée au FabLab est le **FDM** (Fused Deposition Modeling).
Le principe est de faire fondre un filament plastique pour le déposer couche par couche.
* **Le Bed (Plateau) :** La surface chauffante sur laquelle repose la pièce (axes X/Y ou Z selon les modèles).
* **L'Extruder (Extrudeur) :** Le moteur qui pousse le fil. S'il est déporté, le fil passe dans un tube appelé **Bowden**.
* **La Nozzle (Buse) :** La pièce chaude (environ 200°C) par laquelle sort le plastique. Le diamètre standard est de **0.4mm**.

### 2. Les Matériaux (Filaments)
Nous avons passé en revue les thermoplastiques disponibles :
* **PLA (PolyLactic Acid) :** Le standard. Facile à imprimer, biodégradable, mais craint la chaleur (>60°C). *Utilisé pour la majorité des projets Maker.*
* **PETG :** Plus robuste et résistant aux produits chimiques. Idéal pour des pièces mécaniques.
* **ABS/ASA :** Très résistant (chocs/UV) mais dégage des fumées toxiques et est difficile à imprimer (Warping).
* **TPU :** Matériau flexible (élastomère), utile pour des joints ou pneus, mais s'imprime lentement.

### 3. Règles de conception & Slicing
Pour imprimer, on transforme un fichier 3D (.STL) en instructions machines (.gCode) via un logiciel "Slicer" (PrusaSlicer, Bambu Studio).

**Les paramètres clés retenus :**
* **Remplissage (Infill) :** 15% est suffisant pour la majorité des pièces. Le motif **Gyroid** est recommandé pour une meilleure résistance omnidirectionnelle.
* **Parois (Walls/Shells) :** Mettre 3 ou 4 parois (au lieu de 2) augmente considérablement la solidité de la pièce.
* **Supports :** Nécessaires si une partie de la pièce est "dans le vide". Le mode **Tree (Arbre)** est conseillé car plus facile à retirer et économise de la matière.
* **Tolérances :** Pour emboîter deux pièces, il faut prévoir un jeu fonctionnel d'au moins **0.3mm**.

* ** Astuce Maker :** Pour des assemblages solides, on peut insérer des écrous en métal directement dans le plastique en chauffant l'écrou avec un fer à souder, ou en programmant une pause dans l'impression.

##  Application au Projet LumaDome
Cette séance est critique pour la fabrication de la base de ma lampe.

* **Choix du matériau :** Je partirai sur du **PLA** pour le prototype de la base. Si la chauffe des LEDs est trop importante, je passerai au **PETG**.
* **Stratégie d'impression :**
    * La base cylindrique sera imprimée à plat.
    * Utilisation de **supports "Tree"** uniquement pour les ouvertures (Port USB-C et passage bouton).
    * **Intégration :** Je vais prévoir des plots avec des trous pour insérer des écrous à chaud (heat set inserts) afin de visser le PCB proprement.

### Réalisation Pratique : Support de Téléphone
Pour valider les compétences de la séance (Paramétrage du Slicer + Lancement machine), j'ai réalisé l'impression d'un support pour téléphone.

**Détails de l'impression :**
* **Matériau :** PLA (Matériau standard du Labo).
* **Paramètres Slicer :**
    * Support : quelque support en forme de tree.

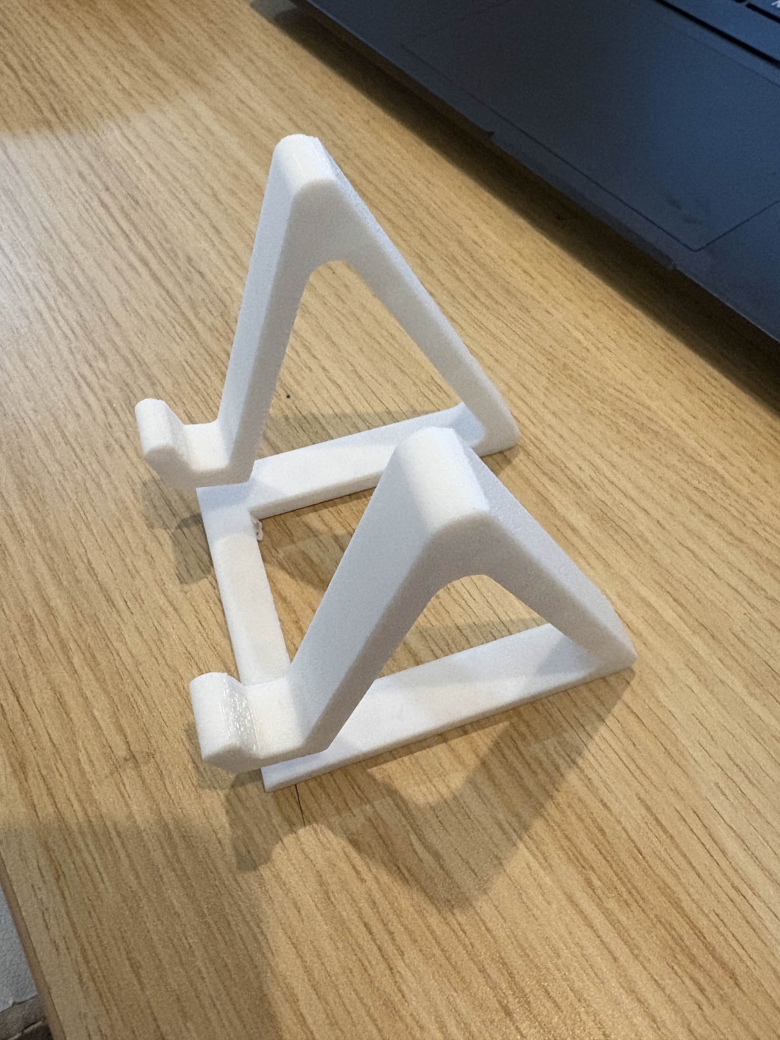
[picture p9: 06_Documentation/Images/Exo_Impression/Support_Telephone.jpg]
Photo du support de téléphone


##  Tâches effectuées
- [x] Découverte des imprimantes du Labo (Creality, Bambu Lab).
- [x] Configuration du Slicer (taille de buse 0.4mm, Température 210°C).
- [x] Lancement  impression test support de téléphone.
- [ ] Lancement de la première impression test (Base LumaDome V1).

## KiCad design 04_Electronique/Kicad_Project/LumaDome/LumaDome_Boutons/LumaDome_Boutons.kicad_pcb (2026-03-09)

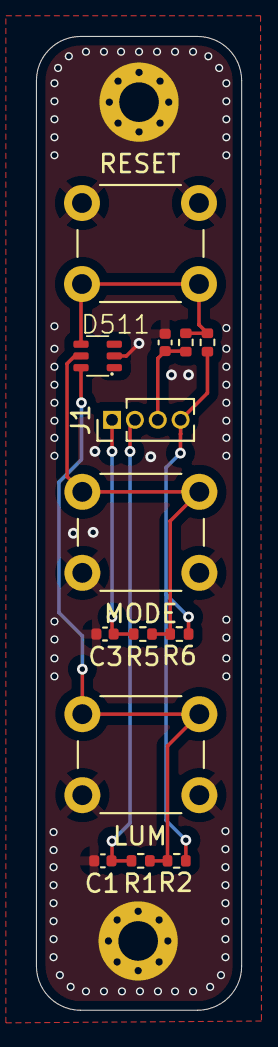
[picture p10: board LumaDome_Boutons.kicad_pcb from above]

Board: 2 copper layers, 11.4 x 54.1 mm, 16 parts (0 on the bottom side), 8 nets.

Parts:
C1, C2, C3: 10n; C_0402_1005Metric
D511: WE 82402375; SC70-6L
H101, H102: MountingHole_Pad; MountingHole_2.2mm_M2_Pad_Via
J1: Conn_01x04; PinHeader_1x04_P1.27mm_Vertical
R1, R2, R3, R4, R5, R6: 10k; R_0402_1005Metric
SW1, SW2, SW3: SW_Push; SW_PUSH_6mm

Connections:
+3.3V: J1.4, R2.2, R4.2, R6.2
/Luminosity_b: D511.6 (I/O), R1.2, R2.1, SW3.1
/Luminosity_button: C1.1, J1.2, R1.1
/Mode_b: D511.5 (I/O), R5.2, R6.1, SW1.1
/Mode_button: C3.1, J1.1, R5.1
/Reset_b: D511.4 (I/O), R3.2, R4.1, SW2.1
/Reset_button: C2.1, J1.3, R3.1
GND: C1.2, C2.2, C3.2, D511.2 (GND), H101.1, H102.1, SW1.2, SW2.2, SW3.2

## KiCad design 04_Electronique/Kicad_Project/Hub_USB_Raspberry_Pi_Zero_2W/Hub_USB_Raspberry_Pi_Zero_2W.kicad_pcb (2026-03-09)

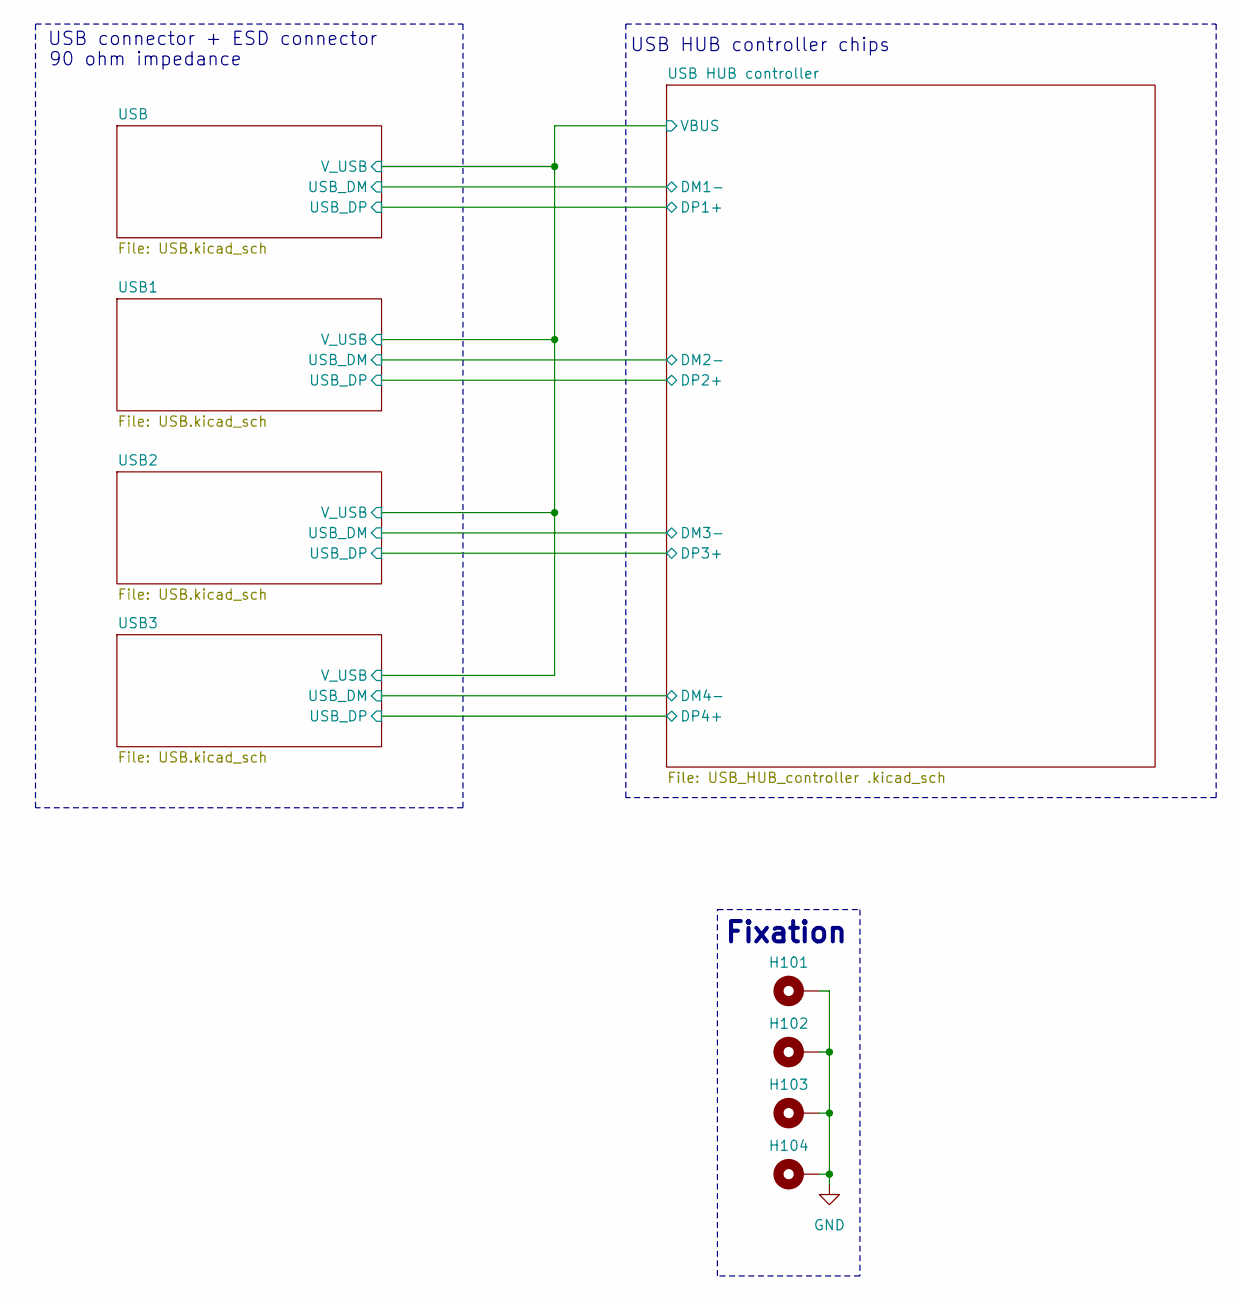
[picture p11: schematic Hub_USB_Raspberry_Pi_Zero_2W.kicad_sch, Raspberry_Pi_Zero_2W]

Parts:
H101, H102, H103, H104: MountingHole_Pad; MountingHole_2.5mm_Pad_Via

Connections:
GND: H101.1, H102.1, H103.1, H104.1; also elsewhere on the board

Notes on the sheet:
90 ohm impedance
USB HUB controller chips
USB connector + ESD connector
Fixation

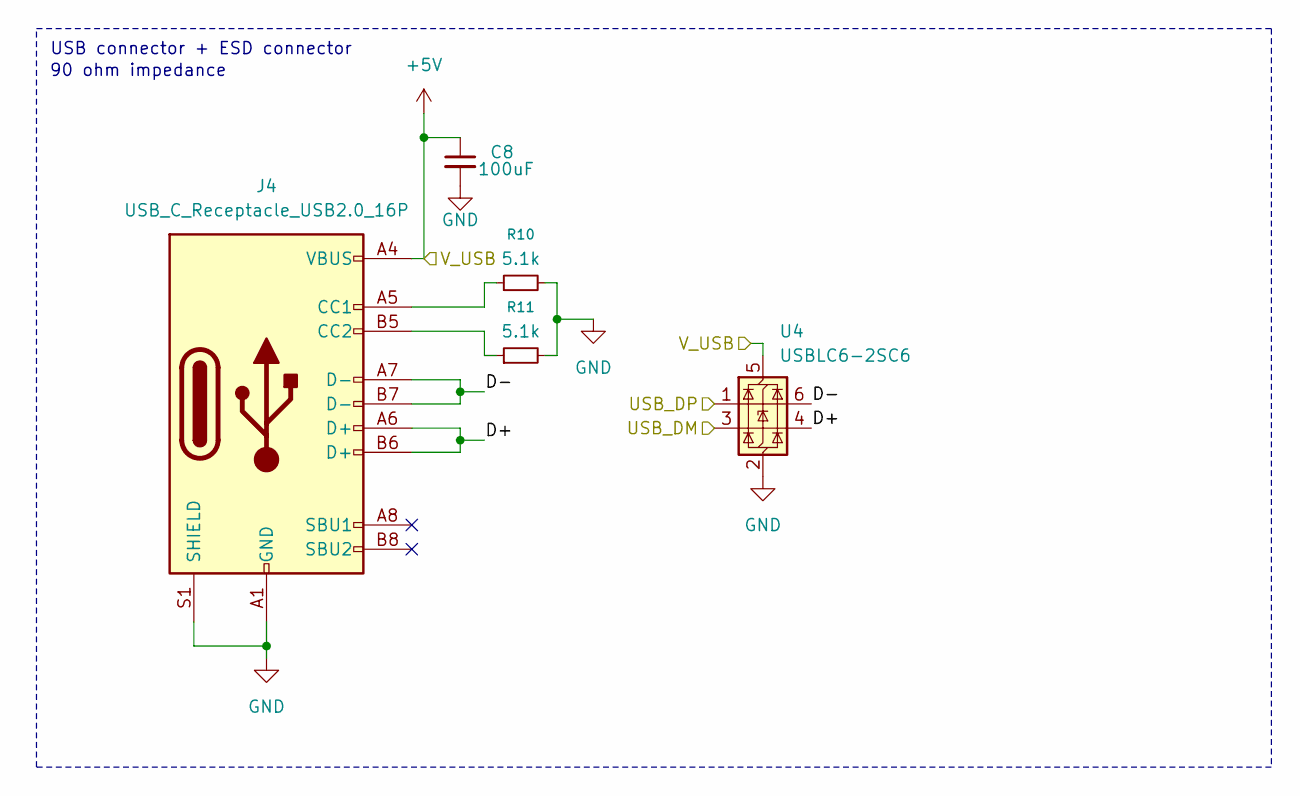
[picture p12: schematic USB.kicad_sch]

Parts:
C8: 100uF; C_0603_1608Metric
J4: USB_C_Receptacle_USB2.0_16P; USB_C_Receptacle_GCT_USB4105-xx-A_16P_TopMnt_Horizontal; MPN 640-USB4105-GF-A
R10, R11: 5.1k; R_0603_1608Metric
U4: USBLC6-2SC6; SOT-23-6; MPN 511-USBLC6-2SC6

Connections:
+5V: C8.1, J4.A4 (VBUS), J4.A9 (VBUS), J4.B4 (VBUS), J4.B9 (VBUS), U4.5 (VBUS); also elsewhere on the board
/USB3/D+: J4.A6 (D+), J4.B6 (D+), U4.4 (I/O2)
/USB3/D-: J4.A7 (D-), J4.B7 (D-), U4.6 (I/O1)
/USB HUB controller/DM4-: U4.3 (I/O2); also elsewhere on the board
/USB HUB controller/DP4+: U4.1 (I/O1); also elsewhere on the board
GND: C8.2, J4.A1 (GND), J4.A12 (GND), J4.B1 (GND), J4.B12 (GND), J4.S1 (SHIELD), R10.2, R11.2, U4.2 (GND); also elsewhere on the board
unnamed: J4.A5 (CC1), R10.1
unnamed: J4.B5 (CC2), R11.1

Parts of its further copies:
C6, C7: 100uF; C_0603_1608Metric
J2, J3: USB_C_Receptacle_USB2.0_16P; USB_C_Receptacle_GCT_USB4105-xx-A_16P_TopMnt_Horizontal; MPN 640-USB4105-GF-A
R3, R4, R300, R400: 5.1k; R_0603_1608Metric
U2, U3: USBLC6-2SC6; SOT-23-6; MPN 511-USBLC6-2SC6

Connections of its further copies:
+5V: C6.1, C7.1, J2.A4 (VBUS), J2.A9 (VBUS), J2.B4 (VBUS), J2.B9 (VBUS), J3.A4 (VBUS), J3.A9 (VBUS), J3.B4 (VBUS), J3.B9 (VBUS), U2.5 (VBUS), U3.5 (VBUS); also elsewhere on the board
/USB1/D+: J2.A6 (D+), J2.B6 (D+), U2.4 (I/O2)
/USB1/D-: J2.A7 (D-), J2.B7 (D-), U2.6 (I/O1)
/USB2/D+: J3.A6 (D+), J3.B6 (D+), U3.4 (I/O2)
/USB2/D-: J3.A7 (D-), J3.B7 (D-), U3.6 (I/O1)
/USB HUB controller/DM2-: U2.3 (I/O2); also elsewhere on the board
/USB HUB controller/DM3-: U3.3 (I/O2); also elsewhere on the board
/USB HUB controller/DP2+: U2.1 (I/O1); also elsewhere on the board
/USB HUB controller/DP3+: U3.1 (I/O1); also elsewhere on the board
GND: C6.2, C7.2, J2.A1 (GND), J2.A12 (GND), J2.B1 (GND), J2.B12 (GND), J2.S1 (SHIELD), J3.A1 (GND), J3.A12 (GND), J3.B1 (GND), J3.B12 (GND), J3.S1 (SHIELD), R3.2, R4.2, R300.2, R400.2, U2.2 (GND), U3.2 (GND); also elsewhere on the board
unnamed: J2.A5 (CC1), R300.1
unnamed: J2.B5 (CC2), R400.1
unnamed: J3.A5 (CC1), R3.1
unnamed: J3.B5 (CC2), R4.1

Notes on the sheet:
90 ohm impedance
USB connector + ESD connector

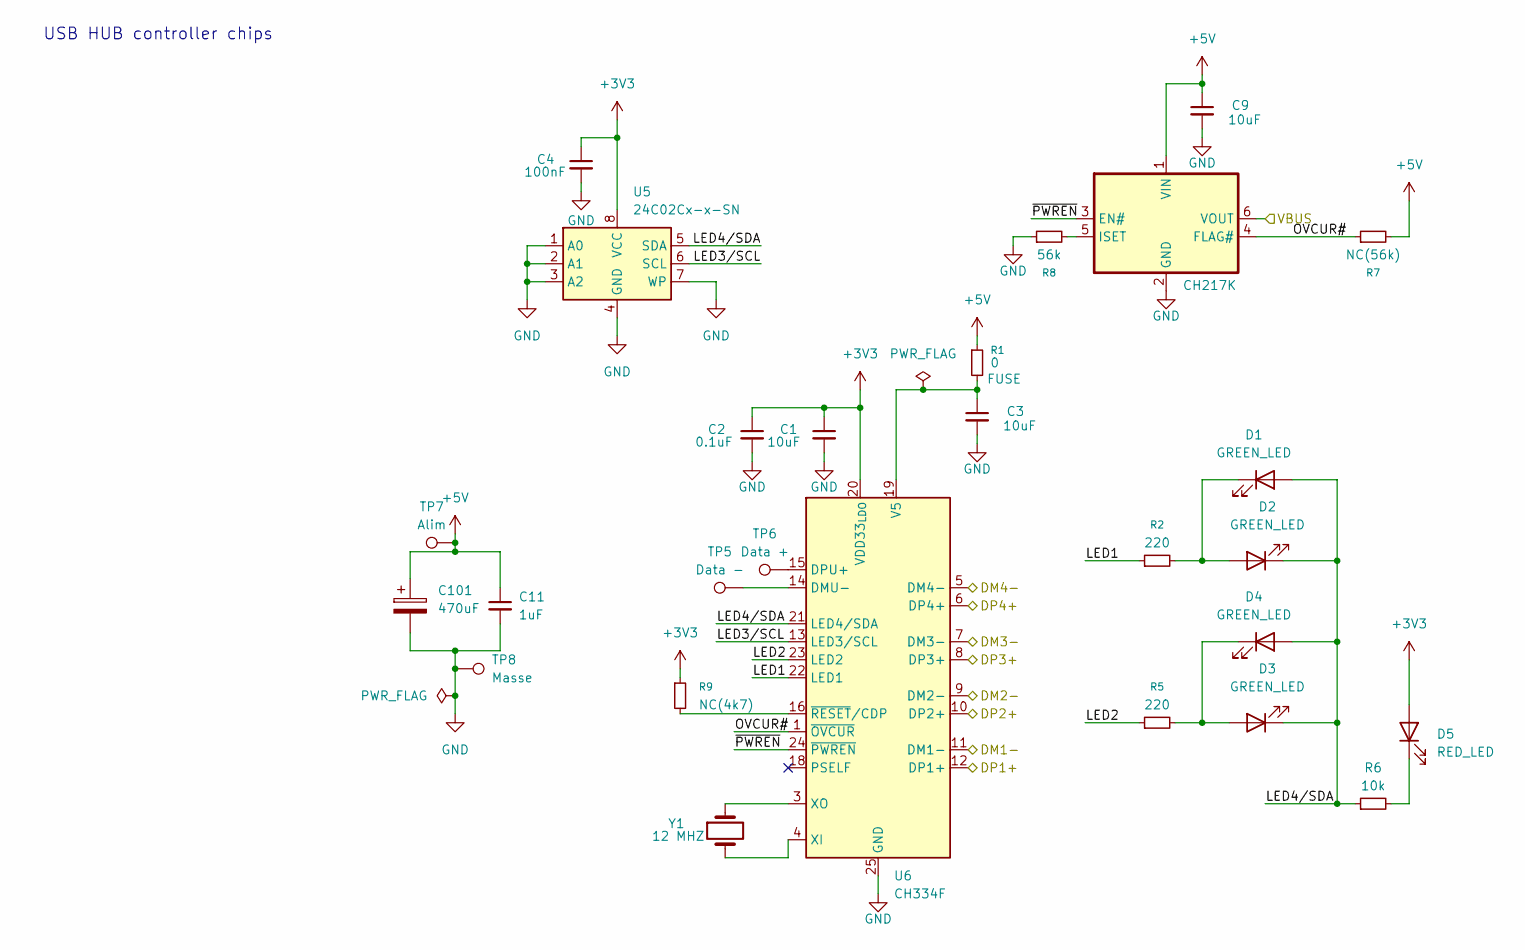
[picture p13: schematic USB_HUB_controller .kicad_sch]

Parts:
C1, C3, C9: 10uF; C_0603_1608Metric
C2: 0.1uF; C_0603_1608Metric
C4: 100nF; C_0603_1608Metric
C11: 1uF; C_0603_1608Metric
C101: 470uF; CP_Elec_10x10.5; MPN 865060657012
CH217K1: CH217K; CH217DS1; MPN C7462749
D1, D2, D3, D4: GREEN_LED; LED_0603_1608Metric
D5: RED_LED; LED_0603_1608Metric
R1: 0; Fuse_0805_2012Metric
R2, R5: 220; R_0603_1608Metric
R6: 10k; R_0603_1608Metric
R7: NC(56k); R_0805_2012Metric
R8: 56k; R_0805_2012Metric
R9: NC(4k7); R_0805_2012Metric
TP5: Data -; TestPoint_Pad_D1.0mm
TP6: Data +; TestPoint_Pad_D1.0mm
TP7: Alim; TestPoint_Pad_D1.5mm
TP8: Masse; TestPoint_Pad_D1.5mm
U5: 24C02Cx-x-SN; SOIC-8_3.9x4.9mm_P1.27mm; MPN 579-24C02CSN
U6: CH334F; QFN-24-1EP_4x4mm_P0.5mm_EP2.7x2.7mm; MPN C5187527
Y1: 12 MHZ; Crystal_SMD_5032-4Pin_5.0x3.2mm

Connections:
+3V3: C1.1, C2.1, C4.1, D5.2 (A), R9.1, U5.8 (VCC), U6.20 (VDD33_{LDO})
+5V: C9.1, C11.1, C101.1, CH217K1.1 (VIN), CH217K1.6 (VOUT), R1.1, R7.2, TP7.1; also elsewhere on the board
/USB HUB controller/DM1-: U6.11 (DM1-); also elsewhere on the board
/USB HUB controller/DM2-: U6.9 (DM2-); also elsewhere on the board
/USB HUB controller/DM3-: U6.7 (DM3-); also elsewhere on the board
/USB HUB controller/DM4-: U6.5 (DM4-); also elsewhere on the board
/USB HUB controller/DP1+: U6.12 (DP1+); also elsewhere on the board
/USB HUB controller/DP2+: U6.10 (DP2+); also elsewhere on the board
/USB HUB controller/DP3+: U6.8 (DP3+); also elsewhere on the board
/USB HUB controller/DP4+: U6.6 (DP4+); also elsewhere on the board
/USB HUB controller/LED1: R2.1, U6.22 (LED1)
/USB HUB controller/LED2: R5.1, U6.23 (LED2)
/USB HUB controller/LED3/SCL: U5.6 (SCL), U6.13 (LED3/SCL)
/USB HUB controller/LED4/SDA: D1.2 (A), D2.1 (K), D3.1 (K), D4.2 (A), R6.1, U5.5 (SDA), U6.21 (LED4/SDA)
/USB HUB controller/OVCUR#: CH217K1.4 (FLAG#), R7.1, U6.1 (~OVCUR)
/USB HUB controller/~PWREN: CH217K1.3 (EN#), U6.24 (~PWREN)
GND: C1.2, C2.2, C3.2, C4.2, C9.2, C11.2, C101.2, CH217K1.2 (GND), R8.1, TP8.1, U5.1 (A0), U5.2 (A1), U5.3 (A2), U5.4 (GND), U5.7 (WP), U6.25 (GND); also elsewhere on the board
unnamed: CH217K1.5 (ISET), R8.2
unnamed: D1.1 (K), D2.2 (A), R2.2
unnamed: D3.2 (A), D4.1 (K), R5.2
unnamed: D5.1 (K), R6.2
unnamed: TP5.1, U6.14 (DMU-)
unnamed: TP6.1, U6.15 (DPU+)
unnamed: C3.1, R1.2, U6.19 (V5)
unnamed: U6.4 (XI), Y1.2
unnamed: U6.3 (XO), Y1.1
unnamed: R9.2, U6.16 (~RESET/CDP)

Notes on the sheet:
USB HUB controller chips

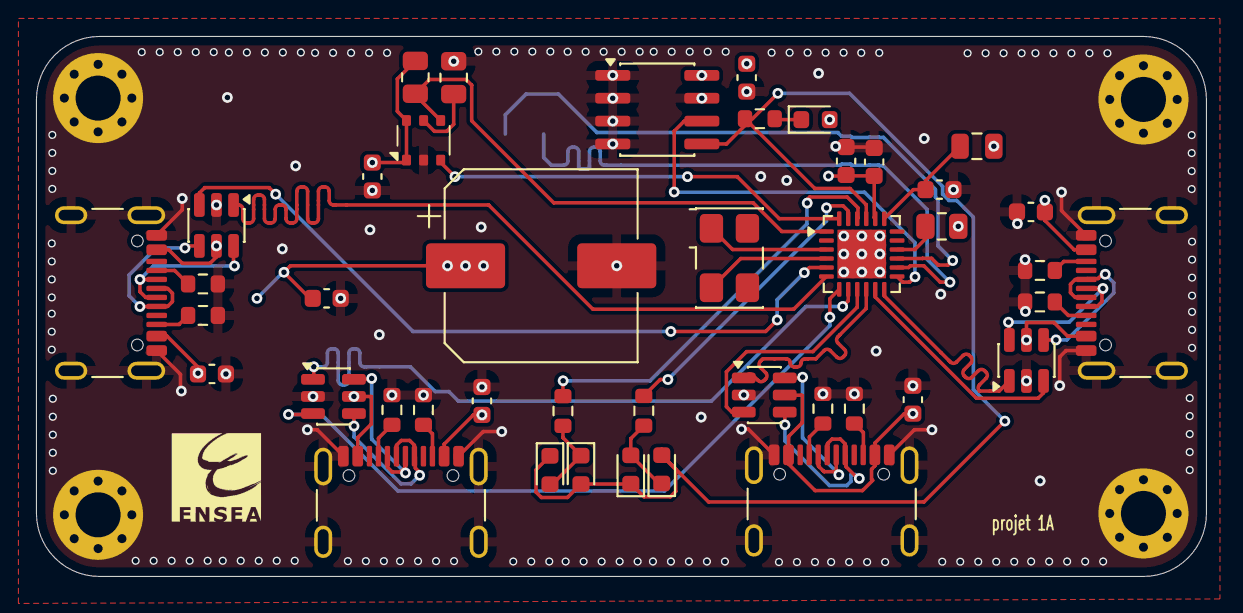
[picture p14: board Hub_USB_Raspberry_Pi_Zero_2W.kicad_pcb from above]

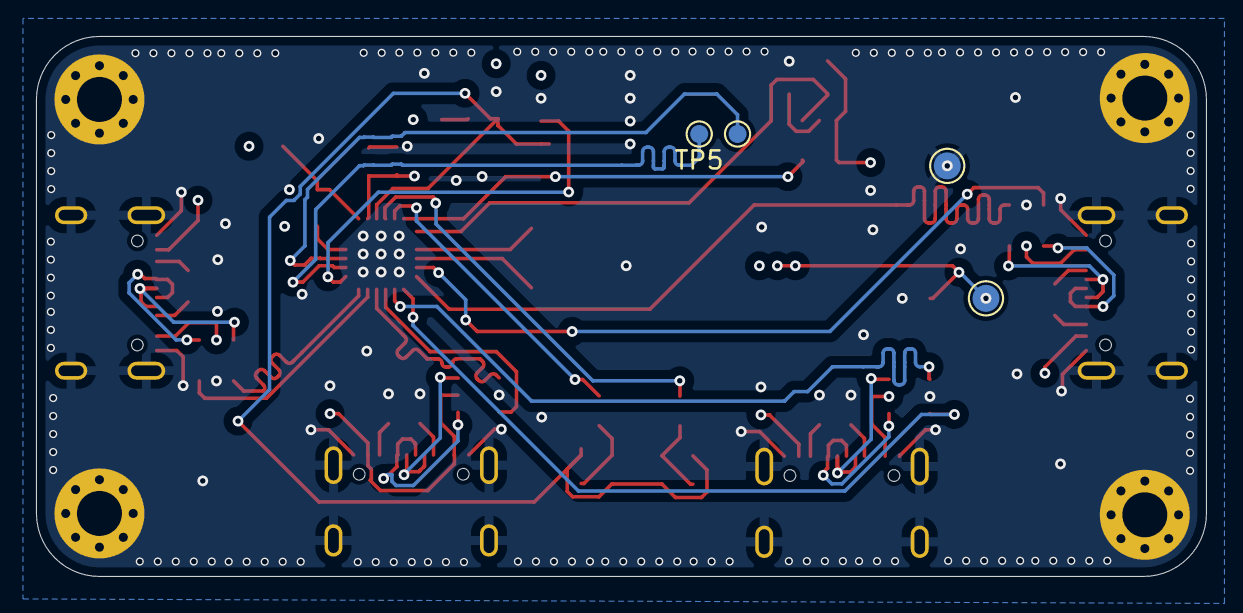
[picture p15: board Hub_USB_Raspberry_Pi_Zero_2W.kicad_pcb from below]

Board: 4 copper layers, 65.0 x 30.0 mm, 51 parts (4 on the bottom side), 43 nets.

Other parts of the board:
C5: 100uF; C_0603_1608Metric
J1: USB_C_Receptacle_USB2.0_16P; USB_C_Receptacle_GCT_USB4105-xx-A_16P_TopMnt_Horizontal
R100, R110: 5.1k; R_0603_1608Metric
U1: USBLC6-2SC6; SOT-23-6

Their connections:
+5V: C5.1, J1.A4 (VBUS), J1.A9 (VBUS), J1.B4 (VBUS), J1.B9 (VBUS), U1.5 (VBUS); also elsewhere on the board
/USB HUB controller/DM1-: U1.3 (I/O2); also elsewhere on the board
/USB HUB controller/DP1+: U1.1 (I/O1); also elsewhere on the board
/USB/D+: J1.A6 (D+), J1.B6 (D+), U1.4 (I/O2)
/USB/D-: J1.A7 (D-), J1.B7 (D-), U1.6 (I/O1)
GND: C5.2, J1.A1 (GND), J1.A12 (GND), J1.B1 (GND), J1.B12 (GND), J1.S1 (SHIELD), R100.2, R110.2, U1.2 (GND); also elsewhere on the board
unnamed: J1.A5 (CC1), R100.1
unnamed: J1.B5 (CC2), R110.1

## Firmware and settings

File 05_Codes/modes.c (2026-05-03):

#include "modes.h"
#include "testLED.h"
#include "tim.h"

// ============================================================
// Conversion coordonnées (col, ligne) → index LED
// Serpentin : colonnes paires montent, impaires descendent
// ============================================================
static int get_led_index(int col, int ligne) {
    if (col % 2 == 0) {
        return col * 8 + ligne;        // Monte
    } else {
        return col * 8 + (7 - ligne);  // Descend
    }
}

// ============================================================
// Mode 0 : Blanc réglable
// ============================================================
void mode_blanc(uint8_t brightness) {
    for (int i = 0; i < NUM_LEDS; i++)
        set_led_rgb(i, brightness, brightness, brightness);
    send_leds();
}

// ============================================================
// Hola : transition entre deux couleurs ligne par ligne
// ============================================================
static void hola_transition(
    uint8_t r1, uint8_t g1, uint8_t b1,
    uint8_t r2, uint8_t g2, uint8_t b2
) {
    for (int ligne = 0; ligne < NUM_LIGNES; ligne++) {
        for (int l = 0; l < ligne; l++)
            for (int j = 0; j < LEDS_PAR_LIGNE; j++)
                set_led_rgb(l * LEDS_PAR_LIGNE + j, r2, g2, b2);

        for (int j = 0; j < LEDS_PAR_LIGNE; j++)
            set_led_rgb(ligne * LEDS_PAR_LIGNE + j, r2, g2, b2);

        for (int l = ligne + 1; l < NUM_LIGNES; l++)
            for (int j = 0; j < LEDS_PAR_LIGNE; j++)
                set_led_rgb(l * LEDS_PAR_LIGNE + j, r1, g1, b1);

        send_leds();
        HAL_Delay(150);
    }
}

// ============================================================
// Mode 1 : Hola Bleu → Vert → Violet → Orange → Bleu
// ============================================================
void mode_hola(void) {
    // Tout en bleu au départ
    for (int i = 0; i < NUM_LEDS; i++)
        set_led_rgb(i, 0, 0, 150);
    send_leds();
    HAL_Delay(500);

    // Hola 1 : Bleu → Vert
    hola_transition(0, 0, 150, 0, 150, 0);
    HAL_Delay(300);

    // Hola 2 : Vert → Violet
    hola_transition(0, 150, 0, 100, 0, 150);
    HAL_Delay(300);

    // Hola 3 : Violet → Orange
    hola_transition(100, 0, 150, 200, 80, 0);
    HAL_Delay(300);

    // Hola 4 : Orange → Bleu
    hola_transition(200, 80, 0, 0, 0, 150);
    HAL_Delay(500);
}

// ============================================================
// Mode 2 : Défilement texte MAXIME
// ============================================================
static const uint8_t font_M[5][6] = {
    {1,1,0,0,1,1},
    {1,1,1,0,0,1},
    {1,0,1,0,0,1},
    {1,1,1,0,0,1},
    {1,1,0,0,1,1}
};
static const uint8_t font_A[5][6] = {
    {0,1,1,1,1,0},
    {1,0,0,0,0,1},
    {1,1,1,1,1,1},
    {1,0,0,0,0,1},
    {1,0,0,0,0,1}
};
static const uint8_t font_X[5][6] = {
    {1,0,0,0,0,1},
    {0,1,0,0,1,0},
    {0,0,1,1,0,0},
    {0,1,0,0,1,0},
    {1,0,0,0,0,1}
};
static const uint8_t font_I[5][6] = {
    {1,1,1,1,1,1},
    {0,0,1,1,0,0},
    {0,0,1,1,0,0},
    {0,0,1,1,0,0},
    {1,1,1,1,1,1}
};
static const uint8_t font_E[5][6] = {
    {1,1,1,1,1,1},
    {1,0,0,0,0,0},
    {1,1,1,1,0,0},
    {1,0,0,0,0,0},
    {1,1,1,1,1,1}
};
static const uint8_t font_space[2][6] = {
    {0,0,0,0,0,0},
    {0,0,0,0,0,0}
};

#define TEXTE_COLS 41
static uint8_t texte[TEXTE_COLS][6];

static void build_texte(void) {
    for (int c=0;c<5;c++) for (int l=0;l<6;l++) texte[c][l]    = font_M[c][l];
    for (int c=0;c<2;c++) for (int l=0;l<6;l++) texte[5+c][l]  = font_space[c][l];
    for (int c=0;c<5;c++) for (int l=0;l<6;l++) texte[7+c][l]  = font_A[c][l];
    for (int c=0;c<2;c++) for (int l=0;l<6;l++) texte[12+c][l] = font_space[c][l];
    for (int c=0;c<5;c++) for (int l=0;l<6;l++) texte[14+c][l] = font_X[c][l];
    for (int c=0;c<2;c++) for (int l=0;l<6;l++) texte[19+c][l] = font_space[c][l];
    for (int c=0;c<5;c++) for (int l=0;l<6;l++) texte[21+c][l] = font_I[c][l];
    for (int c=0;c<2;c++) for (int l=0;l<6;l++) texte[26+c][l] = font_space[c][l];
    for (int c=0;c<5;c++) for (int l=0;l<6;l++) texte[28+c][l] = font_M[c][l];
    for (int c=0;c<2;c++) for (int l=0;l<6;l++) texte[33+c][l] = font_space[c][l];
    for (int c=0;c<5;c++) for (int l=0;l<6;l++) texte[35+c][l] = font_E[c][l];
}

void mode_texte(void) {
    build_texte();

    for (int offset = -8; offset < TEXTE_COLS; offset++) {
        for (int i = 0; i < NUM_LEDS; i++)
            set_led_rgb(i, 0, 0, 0);

        for (int ligne_phys = 0; ligne_phys < 8; ligne_phys++) {
            int col_texte = offset + ligne_phys;
            if (col_texte >= 0 && col_texte < TEXTE_COLS) {
                for (int col_phys = 0; col_phys < 6; col_phys++) {
                    if (texte[col_texte][col_phys]) {
                        int idx = get_led_index(col_phys, ligne_phys);
                        set_led_rgb(idx, 150, 150, 150);
                    }
                }
            }
        }

        send_leds();
        HAL_Delay(200);
    }
}

// ============================================================
// Mode 3 : Koro Sensei
// 0=noir, 1=jaune, 2=blanc
// ============================================================
void mode_koro_sensei(void) {
    uint8_t J_r=200, J_g=180, J_b=0;    // Jaune
    uint8_t B_r=255, B_g=255, B_b=255;  // Blanc
    uint8_t N_r=0,   N_g=0,   N_b=0;    // Noir

    //             L0  L1  L2  L3  L4  L5  L6  L7
    uint8_t grille[6][8] = {
        /* Col 0 */ {0, 1, 1, 1, 1, 1, 1, 0},
        /* Col 1 */ {1, 1, 2, 1, 0, 1, 1, 1},
        /* Col 2 */ {1, 2, 1, 1, 1, 1, 1, 1},
        /* Col 3 */ {1, 2, 1, 1, 1, 1, 1, 1},
        /* Col 4 */ {1, 1, 2, 1, 0, 1, 1, 1},
        /* Col 5 */ {0, 1, 1, 1, 1, 1, 1, 0},
    };

    for (int i = 0; i < NUM_LEDS; i++)
        set_led_rgb(i, 0, 0, 0);

    for (int col = 0; col < 6; col++) {
        for (int ligne = 0; ligne < 8; ligne++) {
            int idx = get_led_index(col, ligne);
            switch (grille[col][ligne]) {
                case 0: set_led_rgb(idx, N_r, N_g, N_b); break;
                case 1: set_led_rgb(idx, J_r, J_g, J_b); break;
                case 2: set_led_rgb(idx, B_r, B_g, B_b); break;
            }
        }
    }

    send_leds();
    HAL_Delay(100);
}

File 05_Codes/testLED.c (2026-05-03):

#include "testLED.h"
#include "modes.h"
#include "tim.h"

// ============================================================
// Projet : LumaDome
// MCU    : STM32 Nucleo-L476RG
// LEDs   : 48x WS2812B (6 colonnes x 8 lignes, serpentin)
// Timer  : TIM3 Channel 1 PWM + DMA
// ============================================================

#define RESET_PULSES  60
#define BUFFER_SIZE   (NUM_LEDS * 24) + RESET_PULSES

// Boutons PCB — Active Low, pull-up sur PCB
#define BTN_MODE_PORT   GPIOC
#define BTN_MODE_PIN    GPIO_PIN_7   // D9

#define BTN_LUMIN_PORT  GPIOB
#define BTN_LUMIN_PIN   GPIO_PIN_6   // D10

#define BTN_RESET_PORT  GPIOB
#define BTN_RESET_PIN   GPIO_PIN_5   // D11

// Bouton bleu Nucleo
#define BTN_BLEU_PORT   GPIOC
#define BTN_BLEU_PIN    GPIO_PIN_13

// Buffer partagé avec modes.c
uint16_t led_buffer[BUFFER_SIZE];

static uint8_t leds_on    = 0;
static uint8_t brightness = 80;
static uint8_t mode_actif = 0; // 0=blanc, 1=hola, 2=texte, 3=koro

// ============================================================
// Callback DMA — stoppe proprement après envoi
// ============================================================
volatile uint8_t dma_done = 0;

void HAL_TIM_PWM_PulseFinishedCallback(TIM_HandleTypeDef *htim) {
    if (htim->Instance == TIM3) {
        HAL_TIM_PWM_Stop_DMA(&htim3, TIM_CHANNEL_1);
        dma_done = 1;
    }
}

// ============================================================
void set_led_rgb(int led_idx, uint8_t r, uint8_t g, uint8_t b) {
    if (led_idx >= NUM_LEDS) return;
    uint32_t color = ((uint32_t)g << 16) | ((uint32_t)r << 8) | b;
    for (int i = 0; i < 24; i++) {
        led_buffer[led_idx * 24 + i] = (color & (1UL << (23 - i))) ? WS2812_1 : WS2812_0;
    }
}

void send_leds(void) {
    dma_done = 0;
    HAL_TIM_PWM_Start_DMA(&htim3, TIM_CHANNEL_1, (uint32_t *)led_buffer, BUFFER_SIZE);
    while (!dma_done);
}

static void eteindre_leds(void) {
    for (int i = 0; i < BUFFER_SIZE; i++) led_buffer[i] = 0;
    send_leds();
    HAL_GPIO_WritePin(LD2_GPIO_Port, LD2_Pin, GPIO_PIN_RESET);
    leds_on    = 0;
    mode_actif = 0;
}

static uint8_t bouton_appuye(GPIO_TypeDef* port, uint16_t pin) {
    if (HAL_GPIO_ReadPin(port, pin) == GPIO_PIN_RESET) {
        HAL_Delay(50);
        if (HAL_GPIO_ReadPin(port, pin) == GPIO_PIN_RESET) {
            while (HAL_GPIO_ReadPin(port, pin) == GPIO_PIN_RESET);
            HAL_Delay(50);
            return 1;
        }
    }
    return 0;
}

// ============================================================
void setup(void) {
    for (int i = 0; i < BUFFER_SIZE; i++) led_buffer[i] = 0;
    eteindre_leds();
}

void loop(void) {
    // Bouton bleu → Toggle ON/OFF
    if (bouton_appuye(BTN_BLEU_PORT, BTN_BLEU_PIN)) {
        if (leds_on) eteindre_leds();
        else {
            leds_on = 1;
            mode_actif = 0;
            mode_blanc(brightness);
        }
    }

    // Mode → cycle entre les modes
    if (bouton_appuye(BTN_MODE_PORT, BTN_MODE_PIN) && leds_on) {
        mode_actif++;
        if (mode_actif > 3) mode_actif = 0;
    }

    // Luminosité → cycle
    if (bouton_appuye(BTN_LUMIN_PORT, BTN_LUMIN_PIN) && leds_on) {
        brightness += 40;
        if (brightness > 200) brightness = 40;
        if (mode_actif == 0) mode_blanc(brightness);
    }

    // Reset → éteint tout
    if (bouton_appuye(BTN_RESET_PORT, BTN_RESET_PIN)) {
        eteindre_leds();
    }

    // Exécution du mode actif
    if (leds_on) {
        switch (mode_actif) {
            case 0: mode_blanc(brightness); HAL_Delay(100); break;
            case 1: mode_hola();            break;
            case 2: mode_texte();           break;
            case 3: mode_koro_sensei();     break;
        }
    }
}

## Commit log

2026-02-02 new pcb raspberry
    [Hub_USB_Raspberry_Pi_Zero_2W.kicad_pcb, Hub_USB_Raspberry_Pi_Zero_2W.kicad_sch, USB.kicad_sch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]
2026-02-05 Update kicad HUB
    [Hub_USB_Raspberry_Pi_Zero_2W.kicad_sch, USB.kicad_sch, USB_HUB_controller .kicad_sch]
2026-02-09 CB avançage
    [Hub_USB_Raspberry_Pi_Zero_2W.kicad_pcb, Hub_USB_Raspberry_Pi_Zero_2W.kicad_sch, USB0.kicad_sch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]
2026-02-09 Finalisation Routage PCB HUB
    [Hub_USB_Raspberry_Pi_Zero_2W.kicad_pcb]
2026-02-16 seance 6et7 + finalisation Kicad
    [Hub_USB_Raspberry_Pi_Zero_2W.kicad_pcb, Hub_USB_Raspberry_Pi_Zero_2W.kicad_sch, USB.kicad_sch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]
2026-03-09 Finalisation premier PCB
    [Drawing 1.dxf, Drawing 2 (2).dxf, First Dome 5cm.stl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]
